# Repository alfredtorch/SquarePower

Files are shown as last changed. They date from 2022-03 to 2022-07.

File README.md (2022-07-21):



__handy, micro power supply__ to drive your projects in all kind of situations! SquarePower fits in any toolbox and in any invention

* connects to an USB-C source, old laptop charger, ... (max 24V)
* outputs a fixed (1,8 V 2,5 V 3,3 V 5V 9V 12V), an adjustable voltage settings (0,8-17V) or simply redirects Vin to Vout
* up to a current 2,1A (max 3A - needs cooling)
* all these specs runs on two separate DCDC converters.. true dual output capable!

# 💊 Features 
__🛒 Easy to source__ : COTS-Principle for cost-efficient creating and repairing</br>
__♻️ Reuse__ : give a second life to your cables and chargers</br>
__🧩 Size__ : weights a few grams fits in +- 30x30x30cm space</br>
__💪🏽 Capable dual output__ : individual On/Off Switch, thermal and shortcircuit protection</br>
__🕶 Flexible__ : runs from a power bank, car battery, wall adaptor</br>
__🪛 DIY Friendly__ : design files & tutorials available</br>

More information about the DCDC Converter can be found [here](https://protosupplies.com/product/mp2315-mini-adjustable-dc-dc-step-down-module/)

# 🔦 Explanation

<p align="center">


</p>

## 🗺 Design Files

Designed in Eagle, in a messy way! Sorry! The related files are available under /Hardware.
Name | Description 
--- | ---
SQUAREPOWERV2 | VIN Vartions :</br>Jack, 3.5mm, horizontal, USB-C Trigger straight, below PCB
SQUAREPOWERVerticalUSBCV1 | VIN Vartions :</br> PCB USB-C right standing or straight, large pads for direct cable soldering

<p align ="center">

</p>

You can order a prepared 10x10cm Panel version directly from DirtyPCB from here. You get a bunch a squarepower pcbs but also a few handy pcb for re-routing 3pin signals, voltage divider and power distributor.
<a rel="dirty" href="https://dirtypcbs.com/store/designer/details/3748/6558/squarepower10x10panelv1-zip">dirty pcb fab house</a>

<p align="center">
  
</p>

## 🛠 For DIY'er:
All you need are steady hands for the soldering part. Small SMD (Surface Mount) components can be tricky to solder for beginners.

## 💰BOM

Bill Of Material: Prices are estimated. Depending on your needs and suppliers, you can cut down the cost so that for one module you will spent less then 3€.

Part Name | Quantity | Price | Supply Link | Notes 
--- | --- | --- | --- | ---
PCB | 1x | 0,3€ | [DirtyPCB](https://dirtypcbs.com/store/designer/details/3748/6558/squarepower10x10panelv1-zip) | Order your own or create the complete manufacturing process on your own 
Mini DCDC | 2x | 1€ | [Aliexpress](https://s.click.aliexpress.com/e/_9hSzDv) | should be based on IC [MP2315](https://www.openhacks.com/uploadsproductos/datasheet_77.pdf)

### Optional components
In case, you don't need any fancy control or feedback but only a way to hack together a DCDC converter, you don't need any of these parts below.
<p align="center">

 </p>

Part Name | Quantity | Price | Supply Link | Notes 
--- | --- | --- | --- | ---
Screw Terminal 4 PIN | 3x | 0,40€ | [Aliexpress](https://s.click.aliexpress.com/e/_9jdwp1) | 2.54mm needs to be 4 pin - KF128
Mini Switch | 2x | 0,1€ | [Aliexpress](https://s.click.aliexpress.com/e/_A2f847) | Carefull, don't stress too much that component
LED | 2x | 0,10€ | [Aliexpress](https://s.click.aliexpress.com/e/_9vGqof) | 0805 - red, white, green... 
Resistors | 3x | 0,1€ | [Aliexpress](https://s.click.aliexpress.com/e/_A0ikLN) | 0805 - I would go for 1kΩ

### Variation : Removable or soldered DCDC converter 
Part Name | Quantity | Price | Supply Link | Notes 
--- | --- | --- | --- | ---
① Screw Terminal 4 PIN | 2x | 0,40€ | [Aliexpress](https://s.click.aliexpress.com/e/_A7x3ar) | 2.54mm needs to be 4 pin - KF128
② Pin header male right angle | 2x | 0,40€ | [Aliexpress](https://s.click.aliexpress.com/e/_9yioMn) | 2.54mm needs to be 4 pin - solder first the dcdc and pin header, before soldering it to the main pcb.

### Variation : Vout Terminals
Part Name | Quantity | Price | Supply Link | Notes 
--- | --- | --- | --- | ---
① Plug Screw Terminal | 2x | 0,30€ | [Aliexpress](https://s.click.aliexpress.com/e/_A9i5w7) | 3.5mm needs to be 2 pin - KF2EDG </br>can be straight or right angle **_OR_**            
② Screw Terminal | 2x | 0,30€ | [Aliexpress](https://s.click.aliexpress.com/e/_9GXJgJ) | 3.5mm needs to be 2 pin - KF350 **_OR_**       
② Screw Terminal 2.54mm | 2x | 0,30€ | [Aliexpress](https://s.click.aliexpress.com/e/_A7x3ar) | 2.54mm needs to be 2 pin - KF128 or JST XH etc...  

### Variation : Vin Terminals
Part Name | Quantity | Price | Supply Link | Notes 
--- | --- | --- | --- | ---
① Plug Screw Terminal| 2x | 0,30€ | [Aliexpress](https://s.click.aliexpress.com/e/_A9i5w7) | 3.5mm needs to be 2 pin - KF2EDG</br>can be straight or right angle **_OR_**
② Screw Terminal | 2x | 0,30€ | [Aliexpress](https://s.click.aliexpress.com/e/_AYf4Zd) | 3.5mm needs to be 2 pin - KF350</br>can be straight or right angle **_OR_**   
③ USB-C Trigger | 1x | 1,00€ | [Aliexpress](https://s.click.aliexpress.com/e/_9x3zGj) | best results with 20V Version **_OR_**       
⓸ Power Jack | 1x | 0,30€ | [Aliexpress](https://s.click.aliexpress.com/e/_9gR5cj) | 5.5x2.1mm DC-005

🙏 Please if you need to shop for parts, it would be great that you use the supply links below. As they are affilated, you're supporting me directly to continue to deliver new projects to the community! Thank you!
At the moment I have no possibility for a larger production and distribution. Of course, I am ready for any cooperation to industrialize the production.</br>  
 Available on [Tindie](https://www.tindie.com/products/alfredtorch/square-power/)</br>
## 👨🏼‍🏫Tutorials
Soon updates for:
* How to build your own & first steps
* Discover Ohm's Law with an USB Power Meter

## ✔ToDo
- [x] Redesign connections so the switches are symmetrical
- [ ] Add some space for soldering screw terminal right in place
- [ ] Add some tutorials about making and using!
- [ ] Design a nice laser-cutted and 3D printed enclosure
- [ ] Test if possible to arduino-drive the Enable Pin with a BSS138 Level Shifter
- [x] Datasheet : Add 100k Resistor between Vin<--Switch-->Enable Pin

## Licence
This work is licensed under Creative Commons License </br> 

<a href="https://trackgit.com">
trackgit-views
</a>

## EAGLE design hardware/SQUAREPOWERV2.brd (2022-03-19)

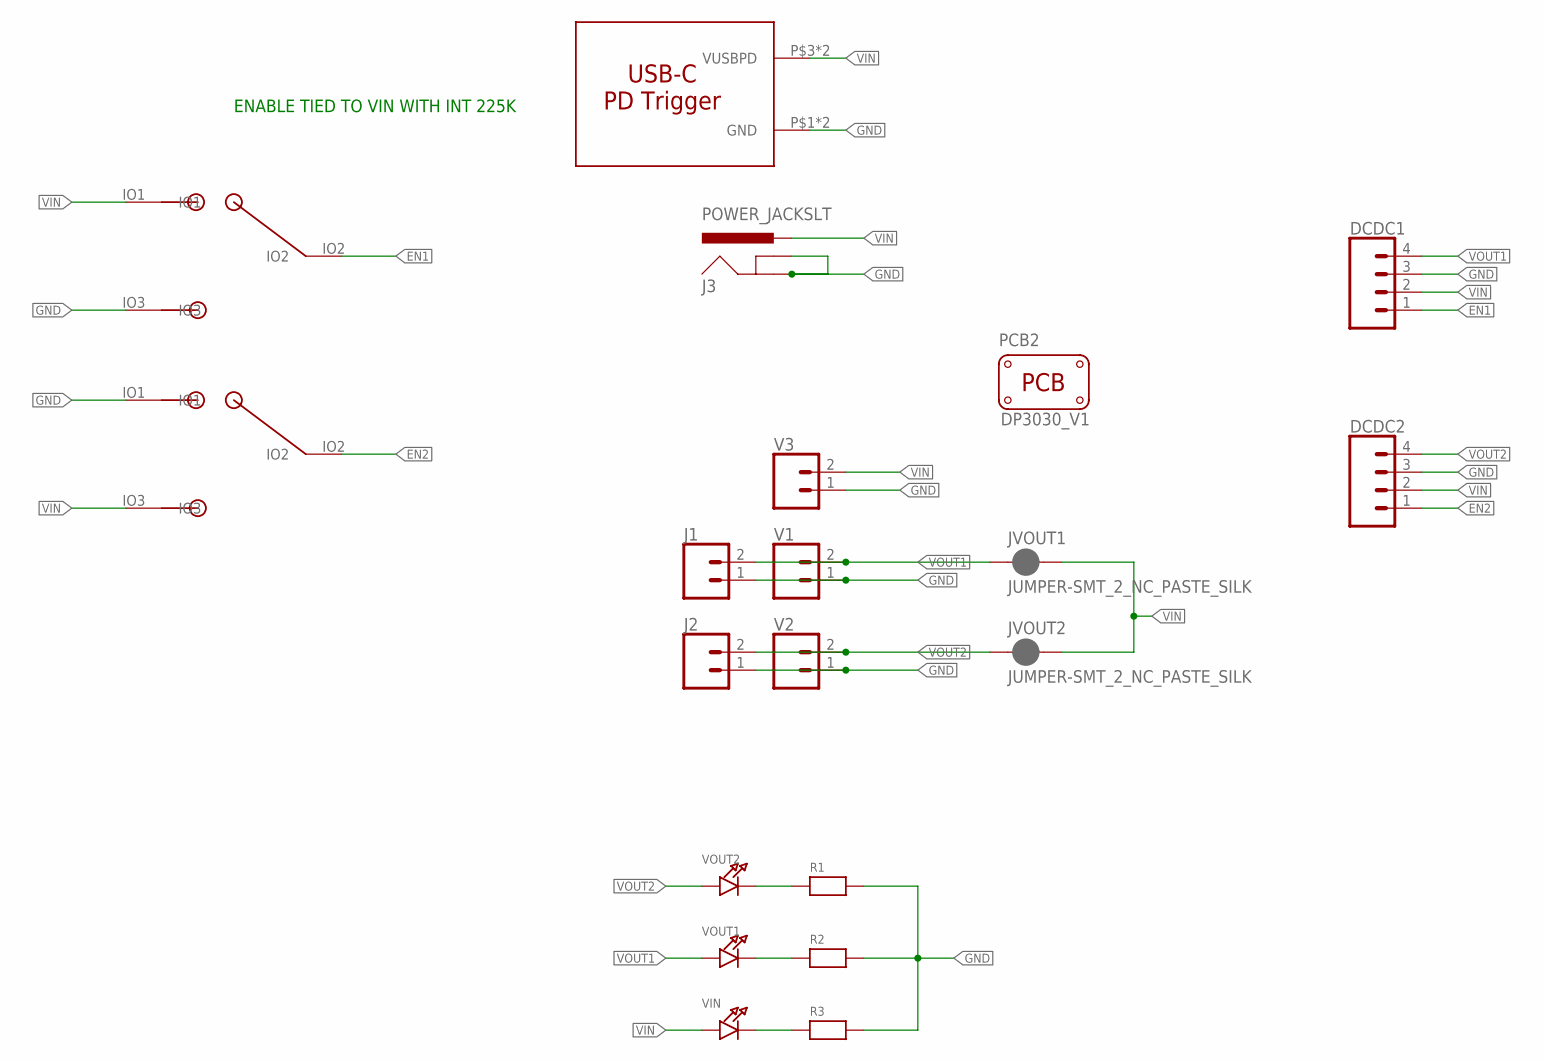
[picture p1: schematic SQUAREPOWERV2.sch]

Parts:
DCDC1, DCDC2: CONN_04LONGPADS; 1X04_LONGPADS
J1, J2: CONN_02; 1X02
J3: POWER_JACKSLT; POWER_JACK_SLOT
JVOUT1, JVOUT2: JUMPER-SMT_2_NC_PASTE_SILK; SMT-JUMPER_2_NC_PASTE_SILK
PCB2: PCB_DP_SQUARE-3X3; DP3030_V1
R1, R2, R3: RESISTOR0805; 0805
U$1, U$2: SPDT-SWITCH-MSKT-12C00; MSKT-12C00
U$5: USB_PD_TRIGGER; USB-PDTRIGGER
V1, V2, V3: CONN_023.5MM; SCREWTERMINAL-3.5MM-2
VIN: LED0805; CHIPLED_0805
VOUT1, VOUT2: LED0805; CHIPLED_0805

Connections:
EN1: DCDC1.1, U$1.IO2
EN2: DCDC2.1, U$2.IO2
GND: DCDC1.3, DCDC2.3, J1.1, J2.1, J3.GND@1 (GNDBREAK), J3.GND@2 (GND), R1.2, R2.2, R3.2, U$1.IO3, U$2.IO1, U$5.P$1 (GND), U$5.P$2 (GND), V1.1, V2.1, V3.1
unnamed: R1.1, VOUT2.C
unnamed: R2.1, VOUT1.C
unnamed: R3.1, VIN.C
VIN: DCDC1.2, DCDC2.2, J3.PWR, JVOUT1.2, JVOUT2.2, U$1.IO1, U$2.IO3, U$5.P$3 (VUSBPD), U$5.P$4 (VUSBPD), V3.2, VIN.A
VOUT1: DCDC1.4, J1.2, JVOUT1.1, V1.2, VOUT1.A
VOUT2: DCDC2.4, J2.2, JVOUT2.1, V2.2, VOUT2.A

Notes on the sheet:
ENABLE TIED TO VIN WITH INT 225K

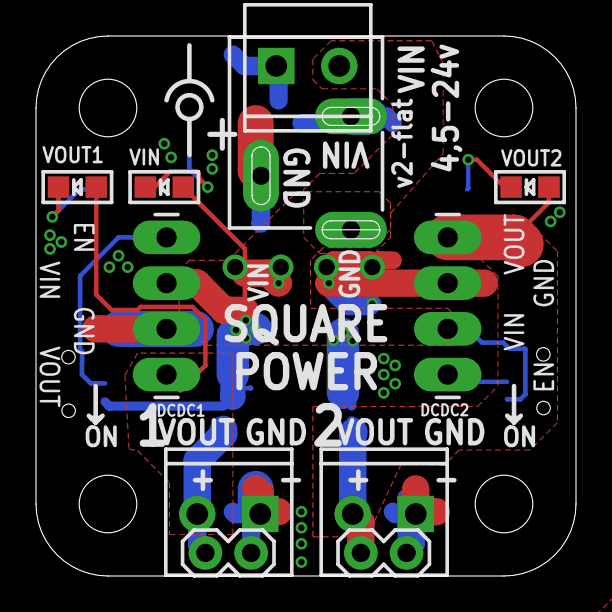
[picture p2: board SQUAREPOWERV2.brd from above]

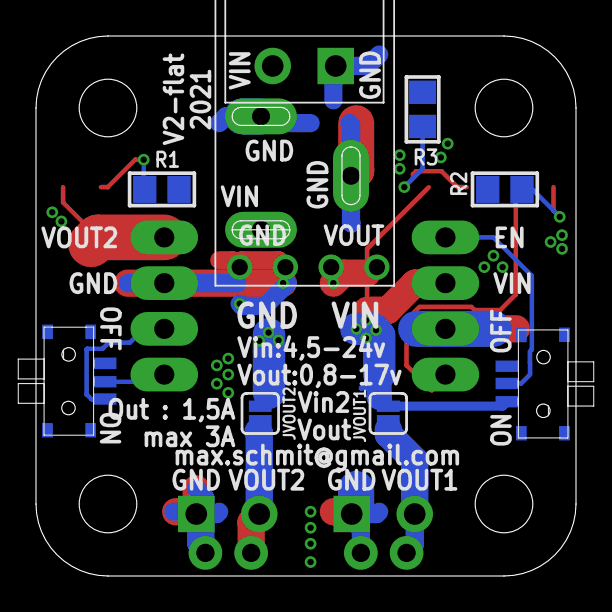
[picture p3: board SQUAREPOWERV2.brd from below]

Board: 2 copper layers, 30.0 x 30.0 mm, 20 parts (8 on the bottom side), 9 nets.

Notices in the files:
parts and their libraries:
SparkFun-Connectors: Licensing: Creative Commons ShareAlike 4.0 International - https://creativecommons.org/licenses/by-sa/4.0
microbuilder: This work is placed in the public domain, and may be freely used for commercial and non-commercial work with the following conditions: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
